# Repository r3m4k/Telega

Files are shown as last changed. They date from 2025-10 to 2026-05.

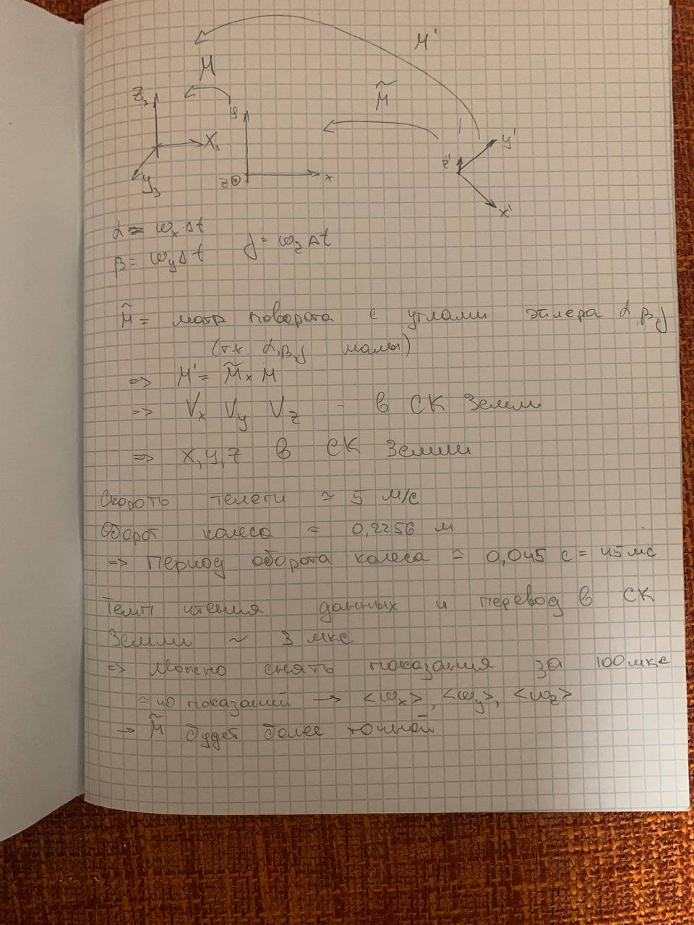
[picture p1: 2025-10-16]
Embedded/Documentation/photo_2024-12-10_16-21-57.jpg

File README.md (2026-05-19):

# Telega

## Структура проекта

Проект состоит из нескольких самостоятельных частей:

- `Embedded` - прошивка для STM32F3Discovery, протокол обмена, драйверы датчиков и прикладная логика МК.
- `Python` - GUI-приложение для ПК, слой связи с МК, сохранение данных и вспомогательные модули анализа.
- `KiCad` - файлы печатной платы. В рамках этого README описывается только наличие раздела, без разбора содержимого.
- `Kompas3d` - механические модели и сборки. Файлы CAD не анализируются подробно.
- `Список комплектующих.csv` - перечень компонентов проекта.

## GUI-приложение для ПК

GUI находится в каталоге `Python` и запускается из `Python/main.py`. Приложение написано на PyQt5 и предназначено для работы с путеизмерительной тележкой через COM-порт: настройка подключения, запуск служебных стадий МК, отображение текущих показаний и сохранение результатов измерений.

### Запуск

Рекомендуемый запуск из корня репозитория:

```bash
python -m venv Python/.venv
Python/.venv/Scripts/pip install -r Python/requirements.txt
Python/.venv/Scripts/python Python/main.py
```

На Linux путь к интерпретатору виртуального окружения будет `Python/.venv/bin/python`.

### Возможности приложения

- выбор директории сохранения и шаблона имени файлов;
- выбор и обновление списка COM-портов;
- запуск рукопожатия с МК после применения настроек;
- запуск калибровки датчиков;
- запуск набора статического буфера перед проездом;
- запуск и завершение измерительного проезда;
- отображение текущих значений `Acc_X`, `Acc_Y`, `Acc_Z`, `Gyro_X`, `Gyro_Y`, `Gyro_Z` и кода ДПП;
- сохранение данных статического буфера и проезда в CSV;
- вывод пользовательских сообщений, предупреждений и ошибок в журнале окна.

Типовой рабочий сценарий описан подробнее в `Python/docs/USER_GUIDE.md`.

### Основные модули

- `Python/main.py` - точка входа, создание `QApplication` и главного окна.
- `Python/gui/main_window.py` - главное окно и state-machine логика пользовательских стадий: настройка, калибровка, статический буфер, готовность к измерению и активное измерение.
- `Python/gui/ui/main_window.ui` - Qt Designer-разметка интерфейса; рядом лежат графические ресурсы `telega.png` и `update.png`.
- `Python/gui/com_port_settings.py` и `Python/gui/saving_params.py` - работа с настройками COM-порта и параметрами сохранения.
- `Python/gui/com_port_reader.py` - мост между GUI и низкоуровневой сессией МК. Запускает отдельный процесс для обмена с устройством и прокидывает данные/события в GUI через Qt-сигналы.
- `Python/gui/data_storage.py` - потоковая запись полученных пакетов `TelegaData` в CSV.
- `Python/gui/data_visualization.py` - обновление LCD-индикаторов текущими значениями телеметрии.
- `Python/telega_session` - проектный слой общения с тележкой: COM-порт, декодер протокола, контроллер команд и функция запуска сессии.
- `Python/async_mc_controller` - более общий асинхронный слой для источников байтов, декодирования, контроллера, шины сигналов, логирования и конфигурации.
- `Python/app_config` и `Python/logger` - конфигурация приложения на Pydantic и настройка логирования.
- `Python/data_analys` и `Python/plotting` - вспомогательные модули для постобработки, фильтрации, расчета траектории и построения графиков.

### Поток данных

После применения настроек главное окно создает конфигурацию COM-порта и запускает `ComPortReader`. Низкоуровневая сессия работает в отдельном процессе через `multiprocessing`, читает байтовый поток с устройства, декодирует пакеты протокола и отправляет в GUI три типа событий: служебные сообщения, телеметрию `TelegaData` и ошибки. Главное окно обновляет индикаторы, пишет данные в открытый CSV-файл и переключает доступные действия пользователя согласно текущей стадии работы.

### Сохраняемые данные

Во время набора статического буфера создается файл вида:

```text
{шаблонное_название}_static_init_{номер_проезда}.csv
```

Во время измерительного проезда создается файл вида:

```text
{шаблонное_название}_measuring_{номер_проезда}.csv
```

CSV пишется в UTF-8 с полями:

```text
PackageNum DppCode AccX AccY AccZ GyroX GyroY GyroZ
```

Настройки приложения сохраняются в `Python/app_config/settings.json`; файл относится к локальным runtime-данным и не обязан храниться в репозитории.

## Прошивка для STM32F3Discovery

Пользовательская часть прошивки расположена в `Embedded/user` и написана как C++-слой поверх STM32F30x Standard Peripheral Library, USB VCP и библиотек датчиков платы STM32F3Discovery. Проект устроен почти как header-only фреймворк: прикладной сценарий находится в `src/main.cpp`, а драйверы, контейнеры, фильтры, протоколы и обвязка периферии вынесены в заголовочные модули `inc`.

### Общая структура

- `src/main.cpp` - точка входа, инициализация оборудования, главный цикл, стадии программы, обработчики команд и системные функции.
- `inc/main.h` - C/C++ мост к STM32 SPL, USB VCP, CMSIS и функциям пользовательского слоя.
- `inc/Common` - общие типы, константы, `TriaxialData` и базовый механизм регистрации обработчиков прерываний.
- `inc/Periph` - GPIO, EXTI и светодиоды платы.
- `inc/Timers` - обертки над аппаратными таймерами STM32, конфигурации и descriptor-классы.
- `inc/Sensors` - драйверы L3GD20, LSM303DLHC и масштабирование датчиков.
- `inc/Filters` - статистика, N-sigma фильтр и фильтр Калмана.
- `inc/DataContainers` - очереди фиксированного размера, включая SPSC-очередь для обмена между IRQ и main.
- `inc/Communication` - сообщения, пакеты, декодеры, USB VCP и USART.
- `inc/aaa_Project_Files` - доменная логика проекта: команды, пакет телеметрии, декодер входящих команд и датчик пройденного пути.

### Инициализация и прерывания

При старте `main()` копирует таблицу векторов прерываний из flash в пользовательскую таблицу `_user_vector_table` в RAM, переключает `SCB->VTOR` на эту таблицу и затем инициализирует оборудование через `InitAll()`. Такой подход позволяет C++-объектам регистрировать собственные обработчики IRQ во время инициализации.

Механизм регистрации прерываний реализован через CRTP-класс `BaseIRQDevice`. Конкретные устройства, например таймеры или EXTI-пины, наследуются от него, сохраняют указатель на активный экземпляр и записывают статический обработчик в пользовательскую таблицу векторов. При срабатывании IRQ статический обработчик перенаправляет вызов в метод `irq_handler()` нужного объекта.

### Основной цикл и стадии программы

Главный цикл прошивки работает как простой диспетчер событий. Сначала он выполняет накопленные отложенные команды из `command_manager.command_queue`, затем при необходимости переключает текущую стадию из `program_stage_queue`, после чего вызывает `init()` новой стадии один раз и `execute()` на каждом проходе цикла.

Поддерживаемые стадии:

- `FooStage` - состояние ожидания: таймеры остановлены, датчики периодически читаются для поддержания их рабочего состояния.
- `CalibrationStage` - калибровка масштабных коэффициентов гироскопа и акселерометра, затем отправка сообщения `END_OF_CALIBRATION`.
- `StaticStage` - статический сбор начальных данных: формируется `InitFrameNum` телеметрических пакетов, после чего отправляется `END_OF_STATIC_INIT`.
- `MeasuringStage` - рабочее измерение: по тику `TIM3` читаются датчики, данные фильтруются, упаковываются и отправляются на ПК.

### Таймеры

В прошивке используются два таймера общего назначения:

- `TIM3` - основной таймер измерений. Его IRQ переключает светодиод `LED9`, выставляет флаг нового периода измерений и увеличивает счетчик времени `tick_counter`.
- `TIM4` - таймер индикации состояния. Его IRQ переключает `LED6` и `LED7`.

Таймеры описаны шаблонными классами `Timer2`, `Timer3`, `Timer4`, которые принимают пользовательский обработчик прерывания как compile-time параметр. Это позволяет вызывать обработчик без виртуальных функций и без runtime-диспетчеризации.

### Датчики и фильтрация

Прошивка работает с датчиками платы STM32F3Discovery:

- `L3GD20` - гироскоп, данные угловой скорости.
- `LSM303DLHC` - акселерометр и температурный датчик; магнитометр в текущей конфигурации отключен.
- `DppSensor` - датчик пройденного пути: импульсы приходят на EXTI-вход `PC1`, направление считывается с `PC3`.

Перед отправкой телеметрии данные акселерометра, гироскопа и температуры проходят через `NSigmaFilter`. Для ускорения и угловой скорости используется фильтр `NSigmaFilter<TriaxialData, 4, 16>`, для температуры - `NSigmaFilter<float, 1, 16>`. Фильтр отбрасывает выбросы по правилу N-sigma и накапливает итоговое среднее.

### Связь с ПК и протокол

Основной канал связи с ПК - USB Virtual COM Port. Входящие данные принимаются в `UserEP3_OUT_Callback()`, преобразуются в `Messages::SizedMessage<VCP_BUFFER_SIZE>` и передаются в `UsbPort`, где поток байтов разбирается `DecoderTelega`.

Входящий командный протокол:

- header: `0xE7 0x7E`;
- format: `0xAB`;
- length: длина поля данных;
- data: код команды;
- checksum: младший байт суммы предыдущих байтов пакета.

`DecoderTelega` отвечает только за входящий поток команд. Он находит команду в списках `urgent_commands` и `deferred_commands` менеджера команд. Срочные команды выполняются сразу в контексте обработчика приема, отложенные команды помещаются в SPSC-очередь и выполняются позже в основном цикле.

Поддерживаемые команды:

- `0xff 0xff` - перезагрузка МК.
- `0xaa 0x00` - переход в `FooStage`.
- `0xaa 0x01` - переход в `CalibrationStage`.
- `0xaa 0x02` - переход в `MeasuringStage`.
- `0xaa 0x03` - переход в `StaticStage`.
- `HANDSHAKE_ACK`, `HEARTBEAT_ACK` - текстовые служебные команды, на которые МК отвечает собственными ACK-сообщениями.

### Исходящие пакеты

Телеметрия отправляется через `TelegaPackage`. Пакет содержит:

- счетчик времени `tick_counter`;
- ускорение `acc_value`;
- угловую скорость `gyro_value`;
- температуру `temp_value`;
- код датчика пройденного пути `dpp_code`;
- контрольную сумму.

Текстовые служебные ответы формируются через `MessagePackage`: подтверждение команды, handshake ACK, heartbeat ACK, сообщение об ошибке, окончание калибровки и окончание статической инициализации.

### Соглашения проекта

Прошивка рассчитана на доверенный ПК-клиент, который отправляет небольшие корректные команды и не перегружает очередь команд. Переполнение очередей и чрезмерная длина входящих пакетов считаются нарушением протокольного соглашения, а не штатным режимом работы. Частота таймера измерений должна быть согласована со временем чтения датчиков, фильтрации и отправки пакета так, чтобы обработка успевала завершиться до следующего периода измерений.

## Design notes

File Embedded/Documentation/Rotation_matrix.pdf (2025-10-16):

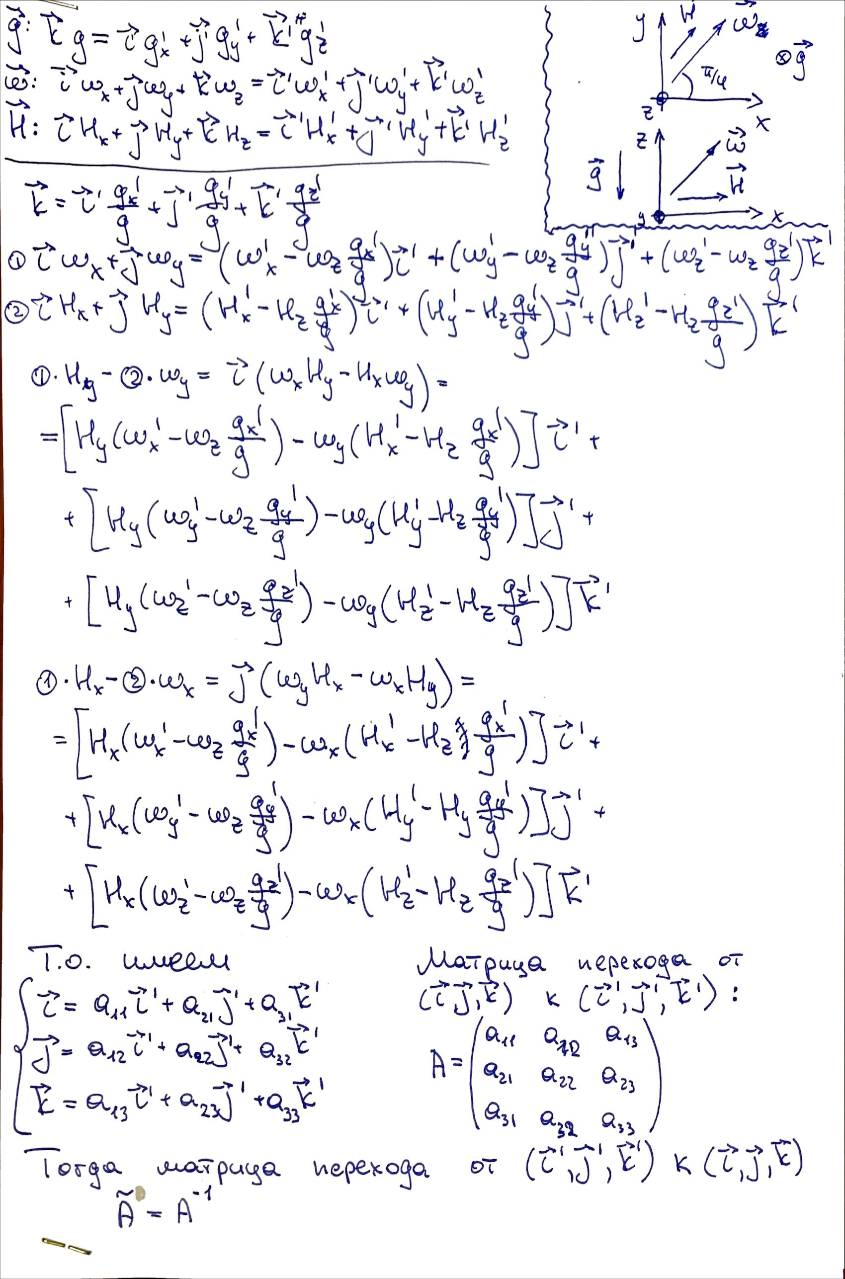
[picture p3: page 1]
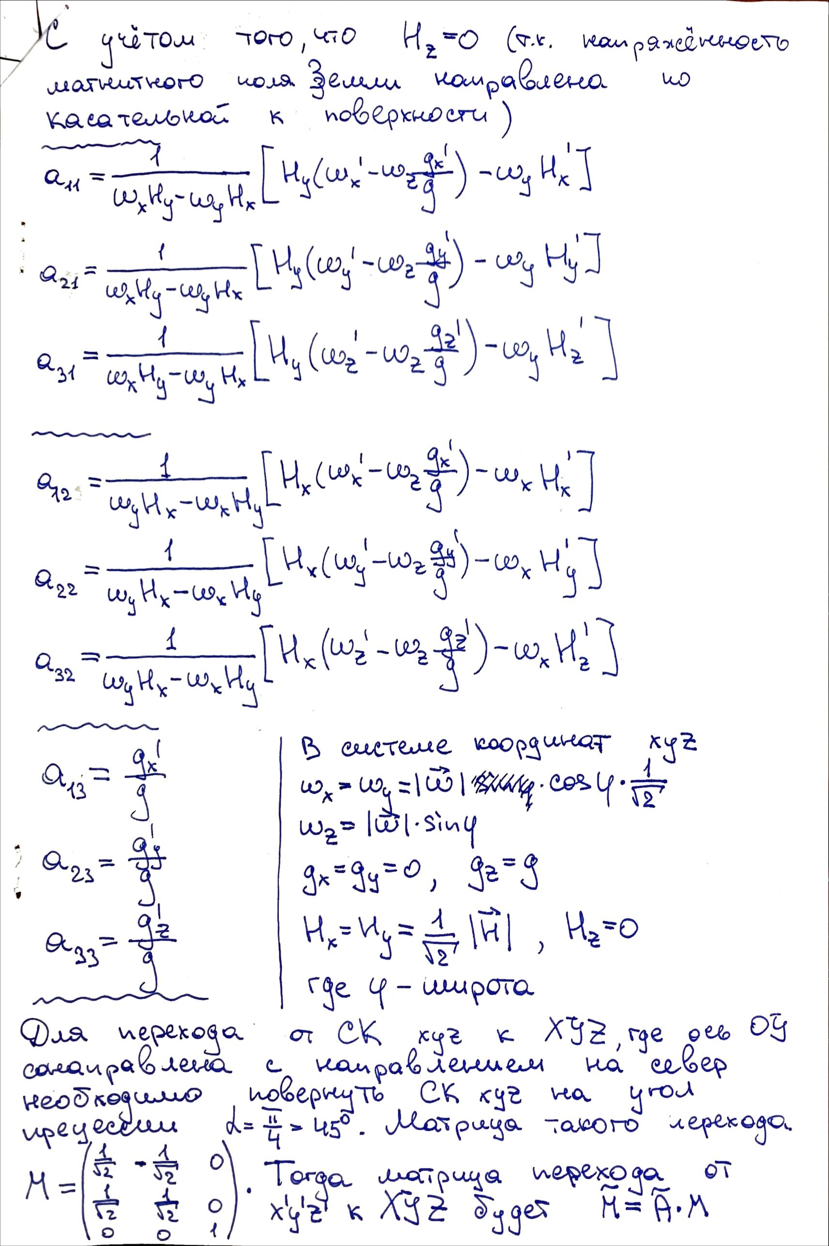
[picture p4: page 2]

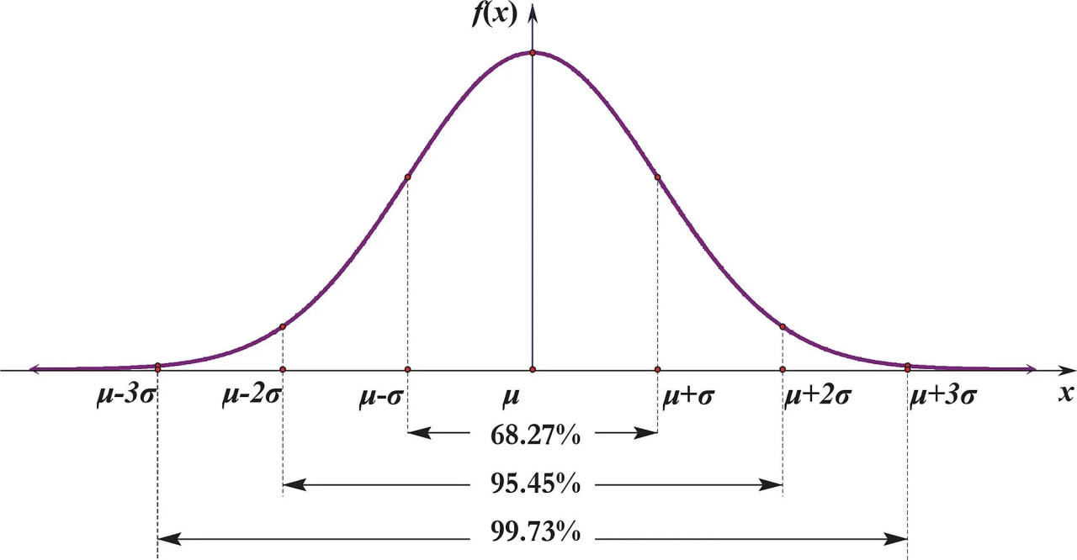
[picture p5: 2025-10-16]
Embedded/Documentation/sigma_rule.jpg

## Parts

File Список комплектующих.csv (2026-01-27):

Номенклатурный номер | Наименование | Бренд | Кол-во | Цена, RUB | Дата доставки | Сумма, RUB
51268 | MF-R135, 1.35А, Предохранитель самовосстанавливающийся, MultiFuse | Bourns | 1 | 20,00 | 3 декабря | 20,00
9000213601 | MTS-101 A-2, Микротумблер ON-OFF SPST 2P 250B/3A | Jietong Switch | 2 | 57,00 | 3 декабря | 114,00
8038550183 | K7815-2000R3 | Mornsun | 1 | 350,00 | 5 декабря | 350,00
36056 | PBD-50 (DS1023-2x25), Гнездо на плату 2.54мм 2х25pin прямое | Connfly | 2 | 30,00 | 3 декабря | 60,00
9000222467 | ВРПИ-М 1,5-(6,3) (ВРПИ-М 1.5-7-0.8), Разъем виброустойчивый плоский 0,5 - 1,5мм² | КВТ | 2 | 12,00 | 3 декабря | 24,00
9001493348 | CDPK0810-101K, 100мкГн, Катушка индуктивности | SCE | 1 | 28,00 | 3 декабря | 28,00
9000565847 | К50-35, 10мкФ, 50В, 105°C, 20%, 5x11мм P:2мм, JRB1H100M02000500110000B, Конденсатор электролитический алюминиевый | JB Capacitors | 1 | 4,00 | 3 декабря | 4,00
9000565854 | К50-35, 22мкФ, 25В, 105°C, 20%, 5x11мм P:2мм, JRB1E220M02000500110000B, Конденсатор электролитический алюминиевый | JB Capacitors | 2 | 4,00 | 3 декабря | 8,00
9000565861 | К50-35, 22мкФ, 50В, 105°C, 20%, 5x11мм P:2мм, JRB1H220M02000500110000B, Конденсатор электролитический алюминиевый | JB Capacitors | 1 | 4,00 | 3 декабря | 4,00
9000461669 | 1N5400, Диод выпрямительный 3А 50В [DO-201AD.] | Diotec | 3 | 18,00 | 3 декабря | 54,00
9001599836 | MAX3232EIDR, Трансивер RS-232, Full-Duplex, 2/2, 250Kbps [SOIC-16.] | Texas Instruments | 2 | 49,00 | 3 декабря | 98,00
8001786468 | K7805-1000R3 | Mornsun | 1 | 190,00 | 5 декабря | 190,00
9001169157 | L7812CV, Стабилизатор напряжения +12В 1.5А [TO-220.] | UMW | 1 | 19,00 | 3 декабря | 19,00
9000811973 | GNL-3012GD, Светодиод зеленый 60° d=3мм 5-10мКд 565нМ (Green) | G-nor | 1 | 9,00 | 3 декабря | 9,00
9000422971 | GNL-3012ED, Светодиод оранжевый 60° d=3мм 8мКд 635нМ (Orange) | G-nor | 1 | 9,00 | 3 декабря | 9,00
9000422970 | GNL-3012YD, Светодиод желтый 60° d=3мм 6мКд 585нМ (Yellow) | G-nor | 1 | 12,00 | 3 декабря | 12,00
9000295626 | MLH-3, Держатель светодиода 3мм металл. | Daier | 3 | 17,00 | 3 декабря | 51,00
9000172308 | 0.33мкФ X7R 16В 10% 0805, CC0805KKX7R7BB334, Конденсатор керамический smd | Yageo | 10 | 5,00 | 3 декабря | 50,00
443350645 | 1 мкФ X7R 16В 10% 0805, GRM21BR71C105K, Конденсатор керамический smd | Murata | 5 | 5,00 | 3 декабря | 25,00
9000896422 | 0.047мкФ X7R 25В 10% 0805, CC0805KRX7R8BB473, Конденсатор керамический smd | Yageo | 5 | 3,00 | 3 декабря | 15,00
9000161208 | 0.25Вт 1206 22 Ом, 1%, RC1206FR-0722RL, Чип резистор (SMD) | Yageo | 10 | 2,00 | 3 декабря | 20,00
 |  |  |  |  | Сумма товаров в заказе, RUB | 1164,00
 |  |  |  |  | Кол-во товаров в заказе | 21

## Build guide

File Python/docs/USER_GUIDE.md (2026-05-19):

# Руководство пользователя

## Назначение

Приложение "Путеизмерительная тележка" предназначено для настройки подключения к микроконтроллеру, калибровки датчиков и сохранения данных проездов в CSV-файлы.

Окно приложения состоит из нескольких основных зон:

- параметры сохранения данных;
- выбор COM-порта;
- индикаторы текущих показаний датчиков;
- кнопки управления процедурой измерений;
- журнал информационных сообщений;
- номер текущего проезда.

## Подготовка к работе

Перед запуском измерений убедитесь, что:

- микроконтроллер подключён к компьютеру;
- COM-порт устройства доступен в системе;
- выбрана директория, куда можно записывать файлы;
- задано шаблонное название файлов.

## Настройка сохранения и подключения

1. В поле `Директория сохранения данных` укажите папку для результатов.
2. В поле `Шаблонное название файлов` укажите базовое имя файлов.
3. В списке `Выбранный com порт` выберите порт микроконтроллера.
4. Если нужного порта нет в списке, нажмите кнопку обновления рядом со списком COM-портов.
5. Нажмите `Применить`.

После применения настроек приложение:

- блокирует изменение параметров сохранения и COM-порта;
- запускает сессию связи с микроконтроллером;
- ожидает рукопожатие с МК;
- выводит результат в журнал информационных сообщений.

Если рукопожатие выполнено успешно, можно запускать калибровку.

## Калибровка датчиков

1. Нажмите `Начать калибровку датчиков`.
2. Дождитесь завершения процедуры.
3. После завершения приложение покажет информационное окно `Калибровка завершена`.
4. Подтвердите сообщение нажатием `OK`.

После калибровки приложение переходит к этапу набора статического буфера.

Повторная калибровка доступна после завершения текущего проезда. При повторной калибровке приложение предупреждает, что текущий цикл подготовки к измерениям будет сброшен и статический буфер нужно будет набрать заново.

## Набор статического буфера

Перед каждым измерением необходимо заново набрать статический буфер.

1. Убедитесь, что тележка находится в состоянии, подходящем для набора статического буфера.
2. Нажмите `Начать сбор статического буфера`.
3. Дождитесь завершения процедуры.
4. После завершения приложение покажет информационное окно `Статический буфер набран`.
5. Подтвердите сообщение нажатием `OK`.

Во время набора статического буфера приложение сохраняет данные в файл:

```text
{шаблонное_название}_static_init_{номер_проезда}.csv
```

Например:

```text
telega_2026-05-19_static_init_1.csv
```

Повторный запуск набора статического буфера во время активной процедуры блокируется.

## Выполнение проезда

После завершения набора статического буфера приложение готово к измерению.

1. Нажмите `Начать проезд`.
2. Выполните проезд тележки.
3. Для завершения измерения нажмите `Завершить проезд`.

Во время проезда приложение сохраняет данные в файл:

```text
{шаблонное_название}_measuring_{номер_проезда}.csv
```

Например:

```text
telega_2026-05-19_measuring_1.csv
```

После завершения проезда:

- текущий CSV-файл закрывается;
- номер текущего проезда увеличивается на 1;
- приложение возвращается к этапу набора статического буфера.

## Последовательность работы

Типовой рабочий цикл выглядит так:

1. Задать директорию сохранения, шаблон файла и COM-порт.
2. Нажать `Применить`.
3. Дождаться успешного рукопожатия с МК.
4. Нажать `Начать калибровку датчиков`.
5. Дождаться сообщения о завершении калибровки.
6. Нажать `Начать сбор статического буфера`.
7. Дождаться сообщения о завершении набора статического буфера.
8. Нажать `Начать проезд`.
9. После окончания проезда нажать `Завершить проезд`.
10. Для следующего проезда снова набрать статический буфер.

## Индикаторы и журнал сообщений

В зоне показаний датчиков отображаются текущие значения:

- `Acc_X`, `Acc_Y`, `Acc_Z`;
- `Gyro_X`, `Gyro_Y`, `Gyro_Z`;
- `Код ДПП`.

Справа расположен журнал `Информационные сообщения`. В него выводятся важные события:

- применение настроек;
- ожидание и результат рукопожатия;
- запуск и завершение калибровки;
- запуск и завершение набора статического буфера;
- запуск и завершение проезда;
- предупреждения и ошибки.

Номер текущего проезда отображается в верхней части окна. Он изменяется автоматически после завершения проезда.

## Ограничения действий

Приложение контролирует порядок работы и предупреждает пользователя, если действие сейчас недоступно.

Нельзя:

- запускать калибровку до применения настроек;
- начинать набор статического буфера до успешной калибровки;
- начинать проезд до завершения набора статического буфера;
- повторно запускать набор статического буфера во время активного набора;
- запускать новый проезд, пока предыдущий не завершён;
- менять параметры сохранения и COM-порт после начала рабочей сессии.

## Завершение работы

Для завершения работы закройте окно приложения стандартной кнопкой закрытия.

При закрытии приложение:

- останавливает сессию связи с микроконтроллером;
- завершает чтение очередей данных;
- закрывает открытый CSV-файл, если он был открыт;
- освобождает ресурсы COM-сессии.

Если проезд был активен, перед закрытием рекомендуется сначала нажать `Завершить проезд`, чтобы текущий файл измерений был закрыт штатно.

## Возможные ошибки

Если приложение сообщает об ошибке задания параметров, проверьте:

- существует ли директория сохранения или можно ли её создать;
- доступна ли директория для записи;
- задано ли корректное шаблонное название файлов;
- выбран ли COM-порт.

Если рукопожатие с МК не выполнено:

- проверьте физическое подключение устройства;
- убедитесь, что выбран правильный COM-порт;
- проверьте, не занят ли порт другой программой;
- повторно примените настройки после устранения причины.

Если возникла ошибка записи CSV:

- проверьте свободное место на диске;
- убедитесь, что файлы результатов не открыты в другой программе с блокировкой записи;
- проверьте права записи в директорию сохранения.

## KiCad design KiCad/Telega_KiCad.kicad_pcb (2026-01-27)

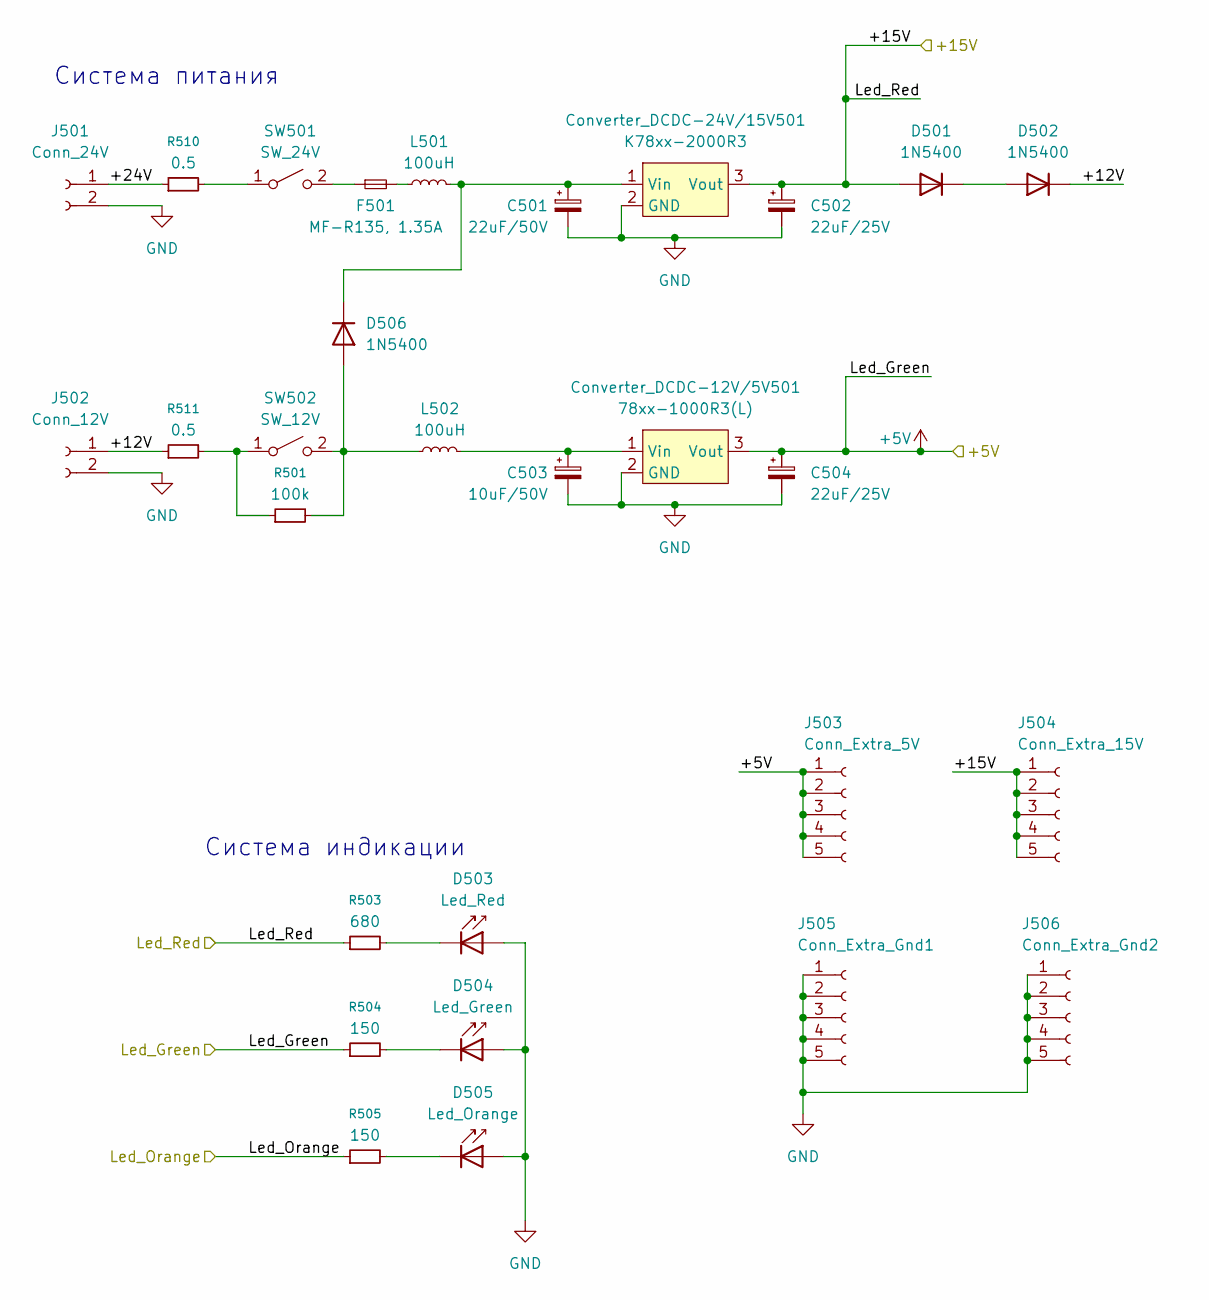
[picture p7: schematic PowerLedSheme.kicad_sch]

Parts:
C501: 22uF/50V; CP_Radial_D8.0mm_P5.00mm
C502, C504: 22uF/25V; CP_Radial_D8.0mm_P5.00mm
C503: 10uF/50V; CP_Radial_D8.0mm_P5.00mm
Converter_DCDC-12V/5V501: 78xx-1000R3(L); Converter_DCDC_RECOM_R-78B-2.0_THT
Converter_DCDC-24V/15V501: K78xx-2000R3; Converter_DCDC_RECOM_R-78B-2.0_THT
D501, D502, D506: 1N5400; D_DO-201AD_P15.24mm_Horizontal
D503: Led_Red; SolderWire-1sqmm_1x02_P5.4mm_D1.4mm_OD2.7mm
D504: Led_Green; SolderWire-1sqmm_1x02_P5.4mm_D1.4mm_OD2.7mm
D505: Led_Orange; SolderWire-1sqmm_1x02_P5.4mm_D1.4mm_OD2.7mm
F501: MF-R135, 1.35А; Fuse_Bourns_MF-RG300
J501: Conn_24V; Molex_KK-254_AE-6410-02A_1x02_P2.54mm_Vertical
J502: Conn_12V; Molex_KK-254_AE-6410-02A_1x02_P2.54mm_Vertical
J503: Conn_Extra_5V; SolderWire-1sqmm_1x05_P5.4mm_D1.4mm_OD2.7mm
J504: Conn_Extra_15V; SolderWire-1sqmm_1x05_P5.4mm_D1.4mm_OD2.7mm
J505: Conn_Extra_Gnd1; SolderWire-1sqmm_1x05_P5.4mm_D1.4mm_OD2.7mm
J506: Conn_Extra_Gnd2; SolderWire-1sqmm_1x05_P5.4mm_D1.4mm_OD2.7mm
L501, L502: 100uH; L_Radial_D9.5mm_P5.00mm_Fastron_07HVP
R501: 100k; R_Axial_DIN0516_L15.5mm_D5.0mm_P25.40mm_Horizontal
R503: 680; R_Axial_DIN0516_L15.5mm_D5.0mm_P25.40mm_Horizontal
R504, R505: 150; R_Axial_DIN0516_L15.5mm_D5.0mm_P25.40mm_Horizontal
R510, R511: 0.5; R_Axial_Power_L38.0mm_W6.4mm_P40.64mm
SW501: SW_24V; SolderWire-1.5sqmm_1x02_P7.8mm_D1.7mm_OD3.9mm
SW502: SW_12V; SolderWire-1.5sqmm_1x02_P7.8mm_D1.7mm_OD3.9mm

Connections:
+5V: C504.1, Converter_DCDC-12V/5V501.3 (Vout), J503.1, J503.2, J503.3, J503.4, J503.5, R504.1; also elsewhere on the board
/+15V: C502.1, Converter_DCDC-24V/15V501.3 (Vout), D501.2 (A), J504.1, J504.2, J504.3, J504.4, J504.5, R503.1; also elsewhere on the board
/Led_Orange: R505.1; also elsewhere on the board
/PowerLedSheme/+12V: D502.1 (K), J502.1, R511.1
/PowerLedSheme/+24V: J501.1, R510.1
GND: C501.2, C502.2, C503.2, C504.2, Converter_DCDC-12V/5V501.2 (GND), Converter_DCDC-24V/15V501.2 (GND), D503.2 (A), D504.2 (A), D505.2 (A), J501.2, J502.2, J505.1, J505.2, J505.3, J505.4, J505.5, J506.1, J506.2, J506.3, J506.4, J506.5; also elsewhere on the board
unnamed: C503.1, Converter_DCDC-12V/5V501.1 (Vin), L502.2
unnamed: C501.1, Converter_DCDC-24V/15V501.1 (Vin), D506.1 (K), L501.2
unnamed: D501.1 (K), D502.2 (A)
unnamed: D503.1 (K), R503.2
unnamed: D504.1 (K), R504.2
unnamed: D505.1 (K), R505.2
unnamed: D506.2 (A), L502.1, R501.2, SW502.2 (B)
unnamed: F501.2, L501.1
unnamed: R510.2, SW501.1 (A)
unnamed: F501.1, SW501.2 (B)
unnamed: R501.1, R511.2, SW502.1 (A)

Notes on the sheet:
Система питания
Система индикации

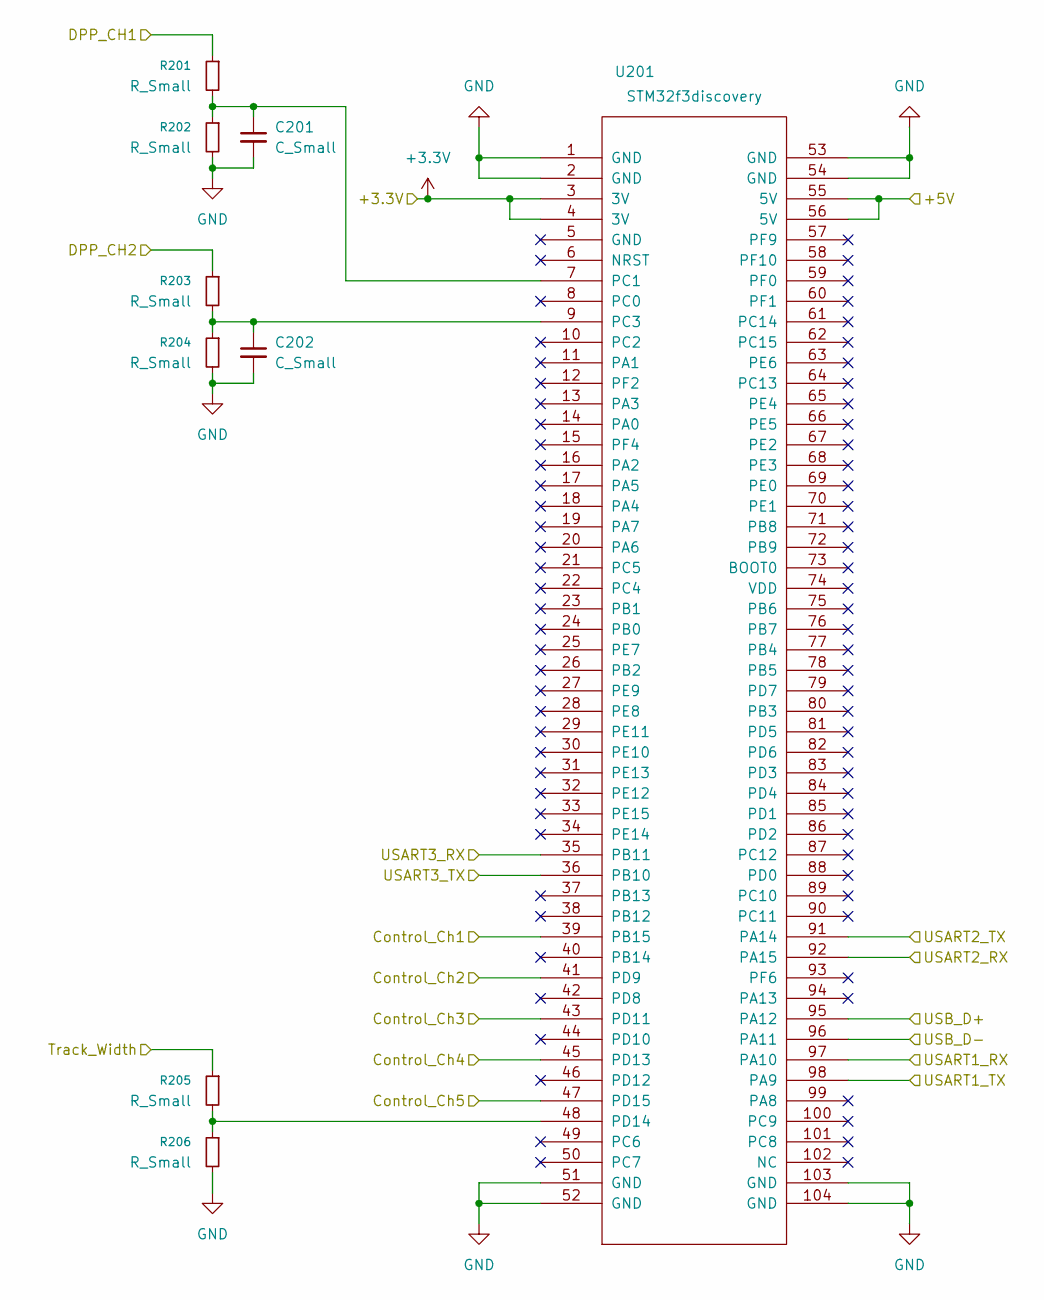
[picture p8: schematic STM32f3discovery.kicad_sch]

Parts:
C201, C202: C_Small; CP_Radial_D8.0mm_P5.00mm
R201, R202, R203, R204, R205, R206: R_Small; R_Axial_DIN0207_L6.3mm_D2.5mm_P15.24mm_Horizontal
U201: STM32f3discovery

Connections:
+3.3V: U201.3 (3V), U201.4 (3V)
+5V: U201.55 (5V), U201.56 (5V); also elsewhere on the board
/Control_Ch1: U201.39 (PB15); also elsewhere on the board
/Control_Ch2: U201.41 (PD9); also elsewhere on the board
/Control_Ch3: U201.43 (PD11); also elsewhere on the board
/Control_Ch4: U201.45 (PD13); also elsewhere on the board
/Control_Ch5: U201.47 (PD15); also elsewhere on the board
/DPP_CH1: R201.1; also elsewhere on the board
/DPP_CH2: R203.1; also elsewhere on the board
/Track_Width: R205.1; also elsewhere on the board
/USART1_RX: U201.97 (PA10); also elsewhere on the board
/USART1_TX: U201.98 (PA9); also elsewhere on the board
/USART2_RX: U201.92 (PA15); also elsewhere on the board
/USART2_TX: U201.91 (PA14); also elsewhere on the board
/USART3_RX: U201.35 (PB11); also elsewhere on the board
/USART3_TX: U201.36 (PB10); also elsewhere on the board
/USB_D+: U201.95 (PA12); also elsewhere on the board
/USB_D-: U201.96 (PA11); also elsewhere on the board
GND: C201.2, C202.2, R202.2, R204.2, R206.2, U201.1 (GND), U201.2 (GND), U201.51 (GND), U201.52 (GND), U201.53 (GND), U201.54 (GND), U201.103 (GND), U201.104 (GND); also elsewhere on the board
unnamed: C201.1, R201.2, R202.1, U201.7 (PC1)
unnamed: C202.1, R203.2, R204.1, U201.9 (PC3)
unnamed: R205.2, R206.1, U201.48 (PD14)

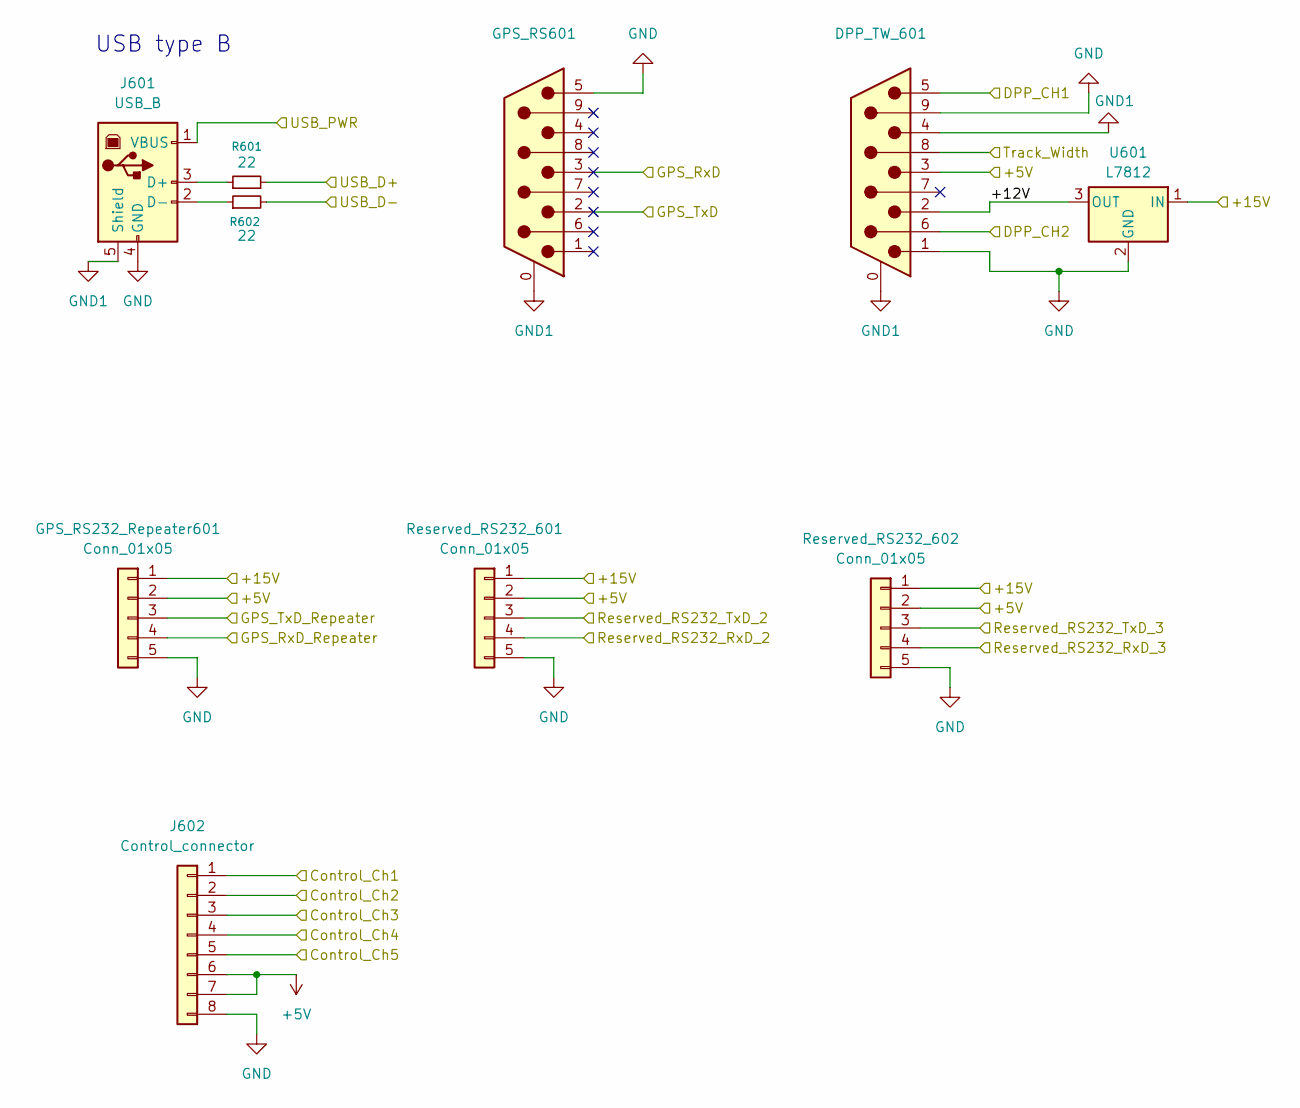
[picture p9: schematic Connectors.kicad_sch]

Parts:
DPP_TW_601: DE9_Pins_MountingHoles; DSUB-9_Pins_Horizontal_P2.77x2.84mm_EdgePinOffset7.70mm_Hou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
GPS_RS232_Repeater601: Conn_01x05; SolderWire-1sqmm_1x05_P5.4mm_D1.4mm_OD2.7mm
GPS_RS601: DE9_Pins_MountingHoles; DSUB-9_Pins_Horizontal_P2.77x2.84mm_EdgePinOffset7.70mm_Hou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
J601: USB_B; USB_B_Lumberg_2411_02_Horizontal
J602: Control_connector; Molex_KK-254_AE-6410-08A_1x08_P2.54mm_Vertical
R601, R602: 22; R_1206_3216Metric
Reserved_RS232_601, Reserved_RS232_602: Conn_01x05; SolderWire-1sqmm_1x05_P5.4mm_D1.4mm_OD2.7mm
U601: L7812; TO-220-3_Vertical

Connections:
+5V: DPP_TW_601.3, GPS_RS232_Repeater601.2, J602.6, J602.7, Reserved_RS232_601.2, Reserved_RS232_602.2; also elsewhere on the board
/+15V: GPS_RS232_Repeater601.1, Reserved_RS232_601.1, Reserved_RS232_602.1, U601.1 (IN); also elsewhere on the board
/Connectors/+12V: DPP_TW_601.2, U601.3 (OUT)
/Control_Ch1: J602.1; also elsewhere on the board
/Control_Ch2: J602.2; also elsewhere on the board
/Control_Ch3: J602.3; also elsewhere on the board
/Control_Ch4: J602.4; also elsewhere on the board
/Control_Ch5: J602.5; also elsewhere on the board
/DPP_CH1: DPP_TW_601.5; also elsewhere on the board
/DPP_CH2: DPP_TW_601.6; also elsewhere on the board
/GPS_RxD: GPS_RS601.3; also elsewhere on the board
/GPS_RxD_Repeater: GPS_RS232_Repeater601.4; also elsewhere on the board
/GPS_TxD: GPS_RS601.2; also elsewhere on the board
/GPS_TxD_Repeater: GPS_RS232_Repeater601.3; also elsewhere on the board
/Led_Orange: J601.1 (VBUS); also elsewhere on the board
/Reserved_RS232_RxD_2: Reserved_RS232_601.4; also elsewhere on the board
/Reserved_RS232_RxD_3: Reserved_RS232_602.4; also elsewhere on the board
/Reserved_RS232_TxD_2: Reserved_RS232_601.3; also elsewhere on the board
/Reserved_RS232_TxD_3: Reserved_RS232_602.3; also elsewhere on the board
/Track_Width: DPP_TW_601.8; also elsewhere on the board
/USB_D+: R601.2; also elsewhere on the board
/USB_D-: R602.2; also elsewhere on the board
GND: DPP_TW_601.1, DPP_TW_601.9, GPS_RS232_Repeater601.5, GPS_RS601.5, J601.4 (GND), J602.8, Reserved_RS232_601.5, Reserved_RS232_602.5, U601.2 (GND); also elsewhere on the board
GND1: DPP_TW_601.0 (PAD), DPP_TW_601.4, GPS_RS601.0 (PAD), J601.5 (Shield)
unnamed: J601.3 (D+), R601.1
unnamed: J601.2 (D-), R602.1

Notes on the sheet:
USB type B

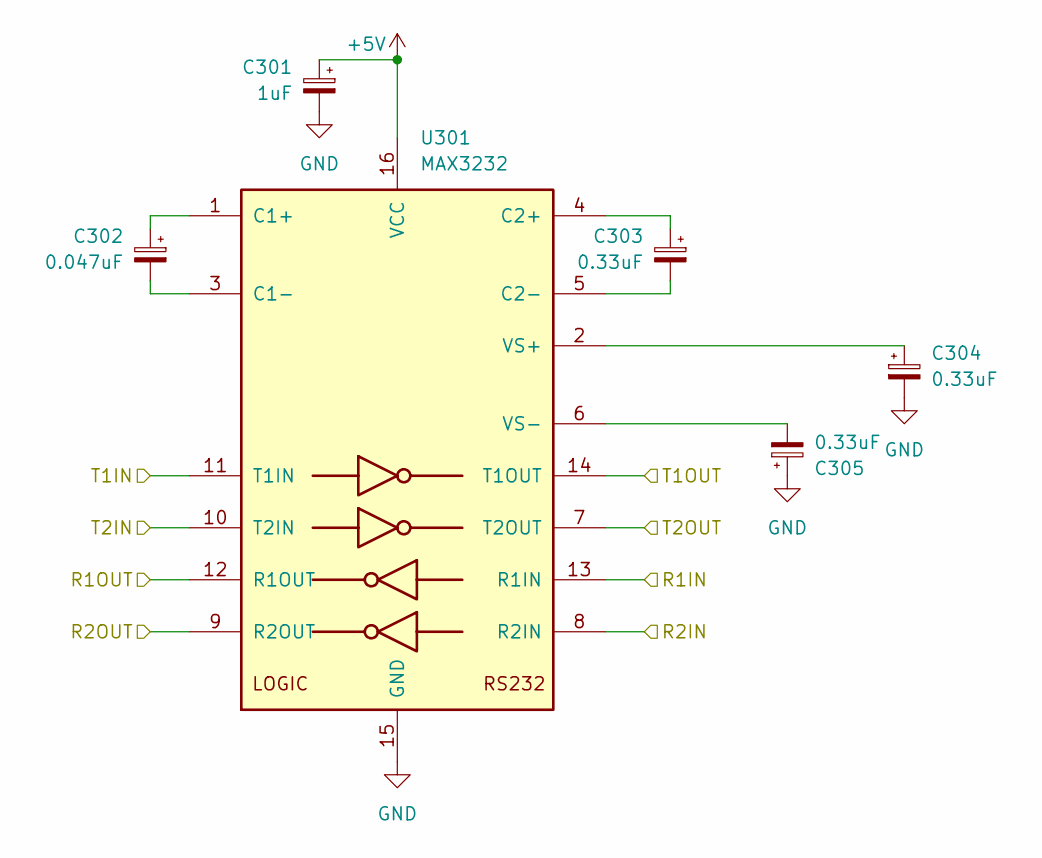
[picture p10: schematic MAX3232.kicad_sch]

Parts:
C301: 1uF; CP_EIA-2012-12_Kemet-R_HandSolder
C302: 0.047uF; CP_EIA-2012-12_Kemet-R_HandSolder
C303, C304, C305: 0.33uF; CP_EIA-2012-12_Kemet-R_HandSolder
U301: MAX3232; SOIC-16W_7.5x10.3mm_P1.27mm

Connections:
+5V: C301.1, U301.16 (VCC); also elsewhere on the board
/GPS_RxD: U301.14 (T1OUT); also elsewhere on the board
/GPS_RxD_Repeater: U301.7 (T2OUT); also elsewhere on the board
/GPS_TxD: U301.13 (R1IN); also elsewhere on the board
/GPS_TxD_Repeater: U301.8 (R2IN); also elsewhere on the board
/USART1_RX: U301.9 (R2OUT), U301.12 (R1OUT); also elsewhere on the board
/USART1_TX: U301.10 (T2IN), U301.11 (T1IN); also elsewhere on the board
GND: C301.2, C304.2, C305.1, U301.15 (GND); also elsewhere on the board
unnamed: C302.1, U301.1 (C1+)
unnamed: C302.2, U301.3 (C1-)
unnamed: C303.1, U301.4 (C2+)
unnamed: C303.2, U301.5 (C2-)
unnamed: C304.1, U301.2 (VS+)
unnamed: C305.2, U301.6 (VS-)

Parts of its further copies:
C401: 1uF; CP_EIA-2012-12_Kemet-R_HandSolder
C402: 0.047uF; CP_EIA-2012-12_Kemet-R_HandSolder
C403, C404, C405: 0.33uF; CP_EIA-2012-12_Kemet-R_HandSolder
U401: MAX3232; SOIC-16W_7.5x10.3mm_P1.27mm

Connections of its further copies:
+5V: C401.1, U401.16 (VCC); also elsewhere on the board
/Reserved_RS232_RxD_2: U401.14 (T1OUT); also elsewhere on the board
/Reserved_RS232_RxD_3: U401.7 (T2OUT); also elsewhere on the board
/Reserved_RS232_TxD_2: U401.13 (R1IN); also elsewhere on the board
/Reserved_RS232_TxD_3: U401.8 (R2IN); also elsewhere on the board
/USART2_RX: U401.12 (R1OUT); also elsewhere on the board
/USART2_TX: U401.11 (T1IN); also elsewhere on the board
/USART3_RX: U401.9 (R2OUT); also elsewhere on the board
/USART3_TX: U401.10 (T2IN); also elsewhere on the board
GND: C401.2, C404.2, C405.1, U401.15 (GND); also elsewhere on the board
unnamed: C402.1, U401.1 (C1+)
unnamed: C402.2, U401.3 (C1-)
unnamed: C403.1, U401.4 (C2+)
unnamed: C403.2, U401.5 (C2-)
unnamed: C404.1, U401.2 (VS+)
unnamed: C405.2, U401.6 (VS-)

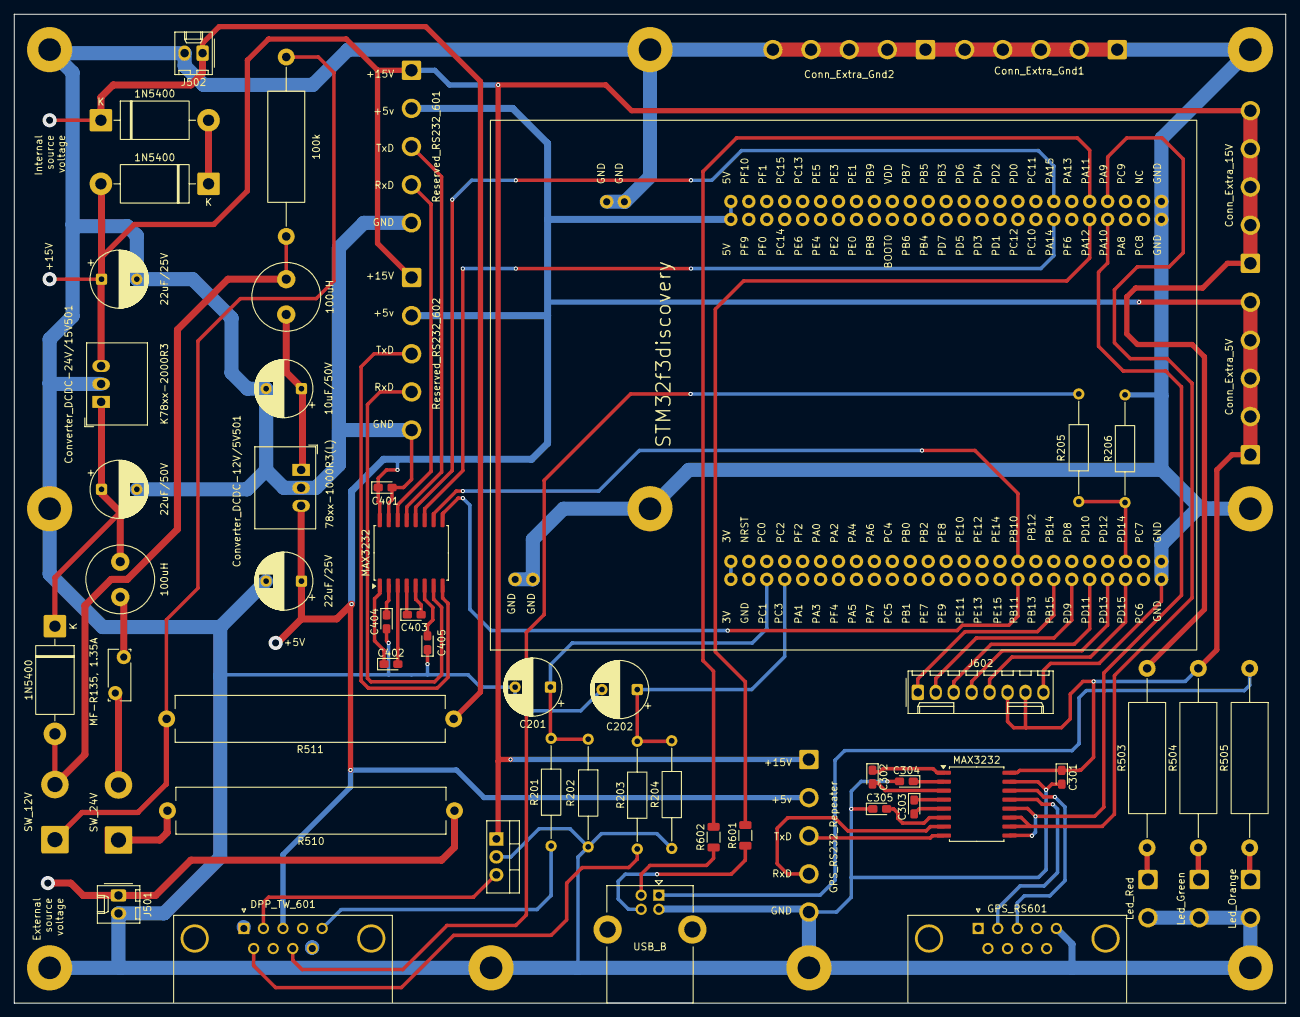
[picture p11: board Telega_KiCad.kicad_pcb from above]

Board: 2 copper layers, 180.0 x 140.0 mm, 60 parts (0 on the bottom side), 61 nets.

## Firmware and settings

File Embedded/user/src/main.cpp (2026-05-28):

/* Includes H files ----------------------------------------------------------*/
#include "main.h"

/* Includes HPP files --------------------------------------------------------*/
#include "Consts.hpp"
#include "GPTimers.hpp"
#include "Leds.hpp"
#include "L3GD20.hpp"
#include "LSM303DLHC.hpp"
#include "DppSensor.hpp"
#include "TelegaPackage.hpp"

#include "RingBuffer.hpp"
#include "UsbPort.hpp"
#include "MessagePackage.hpp"
#include "CommandProcessing.hpp"
#include "NSigmaFilter.hpp"

// ----------------------------------------------------------------------------
//
// Standalone STM32F3 empty sample (trace via NONE).
//
// Trace support is enabled by adding the TRACE macro definition.
// By default the trace messages are forwarded to the NONE output,
// but can be rerouted to any device or completely suppressed, by
// changing the definitions required in system/src/diag/trace_impl.c
// (currently OS_USE_TRACE_ITM, OS_USE_TRACE_SEMIHOSTING_DEBUG/_STDOUT).
//

/* #global variables -----------------------------------------*/
RCC_ClocksTypeDef RCC_Clocks; // structure used for setting up the SysTick Interrupt

// Unused global variables that have to be included to ensure correct compiling
// ###### DO NOT CHANGE ######
// ===============================================================================
__IO uint32_t TimingDelay = 0;                     // used with the Delay function
__IO uint8_t DataReady = 0;
__IO uint32_t USBConnectTimeOut = 100;
__IO uint32_t UserButtonPressed = 0;
__IO uint8_t PrevXferComplete = 1;
__IO uint8_t buttonState;
// ===============================================================================


/* Defines -------------------------------------------------------------------*/
#define IST_VECTORS_NUM     98      // Количество векторов прерываний
#define InitFrameNum        256     // Количество пакетов для выставки

/* Global variables ---------------------------------------------------------*/

typedef void
(* const pHandler)(void);

extern pHandler __isr_vectors[];

/* ****************************************************************************
 * Пользовательские переменные
 *************************************************************************** */

/**
 * @brief   RAM-копия таблицы векторов прерываний.
 * @details 98 векторов занимают 392 байта, поэтому VTOR должен указывать на
 *          адрес, выровненный по ближайшей большей степени двойки: 512 байт.
 */
__attribute__((aligned(512)))
_user_pHandler _user_vector_table[IST_VECTORS_NUM] = {0};

// ----------------------------------------------------------------------------

// Необходимые счётчики и флаг
uint32_t tick_counter = 0;
volatile bool timer_tick_flag = false;

// Счётчик, необходимый для снижения частоты опроса температурного датчика
uint8_t sensor_reading_counter = 0;     

// ----------------------------------------------------------------------------

// Светодиоды на плате
STM_CppLib::Leds leds;

// Обработчик поступивших команд
Commands::CommandManager command_manager;

// Интерфейсы связи
STM_CppLib::UsbPort::UsbPort com_port;

// Используемые таймеры -------------------------------------------------------

// Таймер для чтения данных
STM_CppLib::STM_Timer::Timer3<[](){
    /* Объявление лямбды, которая будет вызываться в прерывании */
    leds.ChangeLedStatus(LED9);
    timer_tick_flag = true;
    tick_counter++;
}>  timer3;

// Таймер для мерцания светодиодами LED6, LED7
STM_CppLib::STM_Timer::Timer4<[](){
    /* Объявление лямбды, которая будет вызываться в прерывании */
    leds.ChangeLedStatus(LED6);
    leds.ChangeLedStatus(LED7);
}>  timer4;     // Таймер для мерцания светодиодами LED6, LED7


/* ****************************************************************************
 * Объявление датчиков, используемых фильтров и пакетов данных
 *
 * Конфигурация датчика пройденного пути:
 * PinPulse:     PC1
 * PinDirection: PC3
 *************************************************************************** */

STM_CppLib::L3GD20      sensor_L3GD20;          // Встроенный гироскоп
STM_CppLib::LSM303DLHC  sensor_LSM303DLHC;      // Встроенный датчик с акселерометром,
                                                // магнитным и температурным датчиками

// Определение пинов для датчика ДПП ------------------------------------------
using PinPulse_t = STM_CppLib::STM_GPIO::GPIO_Pin_EXTI
    <STM_CppLib::STM_GPIO::GPIO_Port::PortC, GPIO_PinSource1, dpp_irq_handler>;

using PinDirection_t = STM_CppLib::STM_GPIO::GPIO_Pin
    <STM_CppLib::STM_GPIO::GPIO_Port::PortC, GPIO_PinSource3>;

Dpp::DppSensor<PinPulse_t, PinDirection_t> dpp_sensor;

// Используемые фильтры
NSigmaFilter<TriaxialData, 4, 16> filter_acc(2.0);     // Фильтр ускорений
NSigmaFilter<TriaxialData, 4, 16> filter_gyro(2.0);    // Фильтр угловой скорости 
NSigmaFilter<float, 1, 16>        filter_temp(2.0);    // Фильтр температуры

// Значения ускорений, угловой скорости и температуры для отправки
TriaxialData acc_value;
TriaxialData gyro_value;
float temp_value;

// Посылка данных
// TODO: в дальнейшем, надо добавить пульт 
Packages::TelegaPackage telega_package(
    &tick_counter, &acc_value, &gyro_value, &temp_value, &dpp_sensor.dpp_code
);

/* ****************************************************************************
 * Описание стадий программы
 *************************************************************************** */

class ProgramStage{
    CommandHandlerFunc init_func;
    CommandHandlerFunc execute_func;
    
public:
    bool is_init = false;

    ProgramStage(CommandHandlerFunc _init_func, CommandHandlerFunc _execute_func):
        init_func(_init_func), execute_func(_execute_func) {}

    void init(){
        init_func();
        is_init = true;
    }

    void execute(){
        execute_func();
    }
};

// -------------------------------------------------------------------------------

// Очередь стадий программ (используется для смены стадий программ).
RingBuffer<ProgramStage*, 2> program_stage_queue;

// Поддерживаемые стадии программы
ProgramStage FooStage(FooStage_init, FooStage_execute);
ProgramStage CalibrationStage(CalibrationStage_init, CalibrationStage_execute);
ProgramStage StaticStage(StaticStage_init, StaticStage_execute);
ProgramStage MeasuringStage(MeasuringStage_init, MeasuringStage_execute);


/* **************************************************************************** */

int main()
{
    /* ***************************************************************************
    * Загрузим собственную таблицу прерываний для возможности её модификации
    *************************************************************************** */

    __disable_irq();    // Отключим прерывания

    // Скопируем исходную таблицу прерываний
    memcpy(_user_vector_table, __isr_vectors, IST_VECTORS_NUM * sizeof(pHandler));

    SCB->VTOR = (uint32_t)_user_vector_table;

    __DSB();    // Ожидаем завершения записи в регистр VTOR
    __ISB();    // Сбрасываем конвейер команд, чтобы следующие инструкции и прерывания
                // использовали новую таблицу векторов

    __enable_irq();     // Включим прерывания

    // ---------------------------------------------------------------------------

    // Получаем текущие значения тактовых частот системы и настроим
    // SysTick для генерации прерываний с периодом 1 мс
    // Если конфигурация SysTick завершилась ошибкой – входим в бесконечный цикл
	RCC_GetClocksFreq(&RCC_Clocks);
	if (SysTick_Config(RCC_Clocks.HCLK_Frequency / 1000))
		while(true) {}
    
    // ---------------------------------------------------------------------------

    // Инициализируем всё оборудования
    InitAll();             
    
    // Поморгаем светодиодами после успешной инициализации
    leds.ToggleLeds();

    // ---------------------------------------------------------------------------

    // Изначально добавим FooStage в program_stage_queue
    program_stage_queue.put(&FooStage);
    ProgramStage* current_stage_ptr = &FooStage;

    // ---------------------------------------------------------------------------
    // Основной цикл программы
    while (true)
    {
        // Выполним все поступившие команды при их наличии
        while (!command_manager.command_queue.is_empty()){
            auto command = command_manager.command_queue.get();
            command.execute();
        }

        // Сменим current_stage_ptr, если есть элементы в очереди program_stage_queue
        if(!program_stage_queue.is_empty()){
            current_stage_ptr->is_init = false;     // Сбросим флаг у текущей стадии
            current_stage_ptr = program_stage_queue.get();
        }

        /* ***********************************************************************
        ШАБЛОН ОТРАБОТКИ СТАДИИ ПРОГРАММЫ:
        Каждая стадия (ProgramStage) отрабатывается по единому принципу:
        1. ИНИЦИАЛИЗАЦИЯ СТАДИИ (однократное выполнение при входе в стадию)
        2. ЦИКЛИЧЕСКОЕ ВЫПОЛНЕНИЕ ОСНОВНОЙ ЛОГИКИ СТАДИИ
        *********************************************************************** */

        if (!current_stage_ptr->is_init){
            current_stage_ptr->init();
        }
        current_stage_ptr->execute();        
    }
}

// -------------------------------------------------------------------------------
// Инициализация оборудования
// -------------------------------------------------------------------------------
void InitAll(){
    leds.Init();
    leds.LedsOn();

    sensor_L3GD20.Init();
    sensor_LSM303DLHC.Init();
    dpp_sensor.Init();
    
    com_port.Init();

    // // Настройка основного таймера с периодом счёта в 250 мс (4 Гц)
    // uint32_t tim3_period = 2500 - 1;
    // Настройка основного таймера с периодом счёта в 100 мс (10 Гц)
    uint32_t tim3_period = 1000 - 1;
    timer3.Init(tim3_period);

    // Настройка таймера для мерцания светодиодами с периодом счёта в 2 с
    uint32_t tim4_period = 20000 - 1;
    timer4.Init(tim4_period);
}

// -------------------------------------------------------------------------------
// Обработчик прерывания от линии Dpp_Channel_1
// -------------------------------------------------------------------------------
void dpp_irq_handler(){
    dpp_sensor.process_front();
}

// -------------------------------------------------------------------------------
// Функции для отработки стадий программы
// -------------------------------------------------------------------------------

// Функция для инициализации FooStage
void FooStage_init(){
    // Выключим все таймеры
    timer3.Stop();
    timer3.ResetCounter();
    timer4.Stop();
    timer4.ResetCounter();
    // Включим все светодиоды
    leds.LedsOn();
}

// Функция для исполнения FooStage 
void FooStage_execute(){
    // Периодическое чтение данных для поддержания температуры кристалла датчиков
    // Возможно, это излишне
    sensor_L3GD20.ReadData();
    sensor_LSM303DLHC.ReadData();
}

// -------------------------------------------------------------------------------

// Функция для инициализации CalibrationStage
void CalibrationStage_init(){
    // Выключим все таймеры
    timer3.Stop();
    timer3.ResetCounter();
    timer4.Stop();
    timer4.ResetCounter();

    // Включим таймер для индикации работы и оба синих светодиода 
    leds.LedsOff();
    leds.LedOn(LED5);
    leds.LedOn(LED8);
    timer4.Start();

}

// Функция для исполнения CalibrationStage 
void CalibrationStage_execute(){

    // Задержка, чтобы отсечь колебания установки от нажатие кнопки оператором
    Delay(2000);

    // Запустим инициализацию масштабирующего коэффициента датчиков
    sensor_L3GD20.InitGyroScaller();
    sensor_LSM303DLHC.InitAccScaller();

    Delay(500);     // Сделаем небольшую паузу перед отправкой сообщения, чтобы ПК успел разобрать предыдущие посылки
    send_end_of_calibration_msg();
    program_stage_queue.put(&FooStage);
}

// -------------------------------------------------------------------------------

// Функция для инициализации StaticStage
void StaticStage_init(){
    tick_counter = 0;
    sensor_reading_counter = 0;
    leds.LedsOff();
    leds.LedOn(LED4);
    leds.LedOn(LED9);
    timer4.ResetCounter();
    timer4.Start();
}

// Функция для исполнения StaticStage
void StaticStage_execute(){

    // Задержка, чтобы отсечь колебания установки от нажатие кнопки оператором
    Delay(2000);

    // Сбросим фильтры перед сбором данных
    filter_acc.reset();
    filter_gyro.reset();
    filter_temp.reset();

    for(int i = 0; i < InitFrameNum; i++){

        /* ***************************************************************
        * Параметры фильтров подобраны так, что все фильтры готовятся за 
        * одинаковое число итераций, что критически важно для корректности 
        * отработки цикла!
        *************************************************************** */

        while(!filter_acc.is_data_filtered() || !filter_gyro.is_data_filtered() || !filter_temp.is_data_filtered()){
            // Считаем значения и добавим полученные значения в фильтры
            sensor_L3GD20.ReadGyro();
            filter_gyro.append_value(sensor_L3GD20.gyro_data);
            
            sensor_LSM303DLHC.ReadAcc();
            filter_acc.append_value(sensor_LSM303DLHC.acc_data);

            // Данные температуры будем считывать в 4 раза реже
            if (sensor_reading_counter++ % 4 == 0) {
                sensor_LSM303DLHC.ReadTemp();
                filter_temp.append_value(sensor_LSM303DLHC.temperature);
            }
        }

        // Обновим данные с датчиков
        acc_value = filter_acc.get_filtered_data();
        gyro_value = filter_gyro.get_filtered_data();
        temp_value = filter_temp.get_filtered_data();

        // Обновим данные в посылке и отправим её по com-порту
        telega_package.UpdateData();
        telega_package.UpdateControlSum();
        com_port.SendPackage(telega_package);

        // Сбросим фильтры
        filter_acc.reset();
        filter_gyro.reset();
        filter_temp.reset();
    }

    // В конце отправим сообщение об окончании выставки
    Delay(500);     // Сделаем небольшую паузу перед отправкой сообщения, чтобы ПК успел разобрать предыдущие посылки
    send_end_of_static_init_msg();
    program_stage_queue.put(&FooStage);
}

// -------------------------------------------------------------------------------

// Функция для инициализации MeasuringStage
void MeasuringStage_init(){
    tick_counter = 0;
    sensor_reading_counter = 0;
    leds.LedsOff();
    // Запустим таймер сбора данных с частотой 4 Гц
    timer3.ResetCounter();
    timer3.Start();
    // Запустим таймер индикации работы
    timer4.ResetCounter();
    timer4.Start();
}

// Функция для исполнения MeasuringStage 
void MeasuringStage_execute(){
    leds.ChangeLedStatus(LED8);

    if (timer_tick_flag){

        /* ***********************************************************************
        * ВАЖНО! Длительность выполнения этой стадии не должна превышать 200мс
        * для обеспечения выдачи данных с частотой 4 Гц. Длительность выполнения
        * можно менять с помощью шаблонных параметров NSigmaFilter.
        *********************************************************************** */

        leds.LedOn(LED5);

        while(!filter_acc.is_data_filtered() || !filter_gyro.is_data_filtered() || !filter_temp.is_data_filtered()){
            // Считаем значения и добавим полученные значения в фильтры
            sensor_L3GD20.ReadGyro();
            filter_gyro.append_value(sensor_L3GD20.gyro_data);

            sensor_LSM303DLHC.ReadAcc();
            filter_acc.append_value(sensor_LSM303DLHC.acc_data);

            // Данные температуры будем считывать в 4 раза реже
            if (sensor_reading_counter++ % 4 == 0) {
                sensor_LSM303DLHC.ReadTemp();
                filter_temp.append_value(sensor_LSM303DLHC.temperature);
            }
        }

        // Обновим данные с датчиков
        acc_value = filter_acc.get_filtered_data();
        gyro_value = filter_gyro.get_filtered_data();
        temp_value = filter_temp.get_filtered_data();

        // Обновим данные в посылке и отправим её по com-порту
        telega_package.UpdateData();
        telega_package.UpdateControlSum();
        com_port.SendPackage(telega_package);

        // Сбросим фильтры
        filter_acc.reset();
        filter_gyro.reset();
        filter_temp.reset();

        leds.LedOff(LED5);
        timer_tick_flag = false;
    }
}

// -------------------------------------------------------------------------------
// Функции для отработки поступивших команд
// -------------------------------------------------------------------------------

void UserEP3_OUT_Callback(uint8_t *buffer){
    Messages::SizedMessage<VCP_BUFFER_SIZE> message(buffer, VCP_BUFFER_SIZE);
    com_port.EP3_OUT_Callback(message);
}

// Функции для обработки поступивших команд
void restart(){
    NVIC_SystemReset();
}

void set_FooStage(){
    program_stage_queue.put(&FooStage);
}

void set_CalibrationStage(){
    program_stage_queue.put(&CalibrationStage);
}

void set_StaticStage(){
    program_stage_queue.put(&StaticStage);;
}

void set_MeasureStage(){
    program_stage_queue.put(&MeasuringStage);
}

// -------------------------------------------------------------------------------
// Отправка предопределённых сообщений
// -------------------------------------------------------------------------------


void send_confirm_msg(){
    const char* text = "CONFIRM_RECEIVED_COMMAND";
    Packages::MessagePackage msg_package(text, strlen(text));
    com_port.SendPackage(msg_package);
}

void send_handshake_ack(){
    const char* text = "TELEGA_STM32_ACK";
    Packages::MessagePackage msg_package(text, strlen(text));
    com_port.SendPackage(msg_package);
}

void send_heartbeat_ack(){
    const char* text = "TELEGA_STM32_ALIVE";
    Packages::MessagePackage msg_package(text, strlen(text));
    com_port.SendPackage(msg_package);
}

void send_error_msg(){
    const char* text = "UNKNOWN_COMMAND";
    Packages::MessagePackage msg_package(text, strlen(text));
    com_port.SendPackage(msg_package);
}

void send_end_of_calibration_msg(){
    const char* text = "END_OF_CALIBRATION";
    Packages::MessagePackage msg_package(text, strlen(text));
    com_port.SendPackage(msg_package);
}

void send_end_of_static_init_msg(){
    const char* text = "END_OF_STATIC_INIT";
    Packages::MessagePackage msg_package(text, strlen(text));
    com_port.SendPackage(msg_package);
}

// -------------------------------------------------------------------------------
// Системные функции
// -------------------------------------------------------------------------------

void Error_Handler(void)
{
    /* Turn LED10/3 (RED) on */
    STM_EVAL_LEDOn(LED10);
    STM_EVAL_LEDOn(LED3);
    while (1)
    {
    }
}

// Function to insert a timing delay of nTime
// ###### DO NOT CHANGE ######
void Delay(__IO uint32_t nTime)
{
    TimingDelay = nTime;

    while (TimingDelay != 0){}
    // for (int i = 0; i < 1000000; i++){}
}

// Function to Decrement the TimingDelay variable.
// ###### DO NOT CHANGE ######
void TimingDelay_Decrement(void)
{
    if (TimingDelay != 0x00)
    {
        TimingDelay--;
    }
}

// Unused functions that have to be included to ensure correct compiling
// ###### DO NOT CHANGE ######
// =======================================================================
uint32_t L3GD20_TIMEOUT_UserCallback(void)
{
    return 0;
}

uint32_t LSM303DLHC_TIMEOUT_UserCallback(void)
{
    return 0;
}
// =======================================================================

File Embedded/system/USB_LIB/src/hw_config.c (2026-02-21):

/**
 ******************************************************************************
 * @file    hw_config.c
 * @author  MCD Application Team
 * @version V1.1.0
 * @date    20-September-2012
 * @brief   Hardware Configuration & Setup.
 ******************************************************************************
 * @attention
 *
 * <h2><center>&copy; COPYRIGHT 2012 STMicroelectronics</center></h2>
 *
 * Licensed under MCD-ST Liberty SW License Agreement V2, (the "License");
 * You may not use this file except in compliance with the License.
 * You may obtain a copy of the License at:
 *
 *        http://www.st.com/software_license_agreement_liberty_v2
 *
 * Unless required by applicable law or agreed to in writing, software
 * distributed under the License is distributed on an "AS IS" BASIS,
 * WITHOUT WARRANTIES OR CONDITIONS OF ANY KIND, either express or implied.
 * See the License for the specific language governing permissions and
 * limitations under the License.
 *
 ******************************************************************************
 */

/* Includes ------------------------------------------------------------------*/
#include "stm32f30x.h"
#include "hw_config.h"
#include "usb_lib.h"
#include "usb_desc.h"
#include "usb_pwr.h"
#include "usb_lib.h"
#include "platform_config.h"
#include "stm32f3_discovery.h"
#include "usb_prop.h"

#include "stm32f30x_it.h"
#include "stm32f30x_gpio.h"
#include "stm32f30x_exti.h"
#include "stm32f30x_rcc.h"
#include "stm32f30x_misc.h"
#include "usb_lib.h"
#include "usb_prop.h"
#include "usb_desc.h"
#include "hw_config.h"
#include "usb_pwr.h"

/** @addtogroup STM32F3-Discovery_Demo
 * @{
 */

/* Private typedef -----------------------------------------------------------*/
/* Private define ------------------------------------------------------------*/
/* Private macro -------------------------------------------------------------*/
/* Private variables ---------------------------------------------------------*/
ErrorStatus HSEStartUpStatus;
EXTI_InitTypeDef EXTI_InitStructure;

extern __IO uint32_t packet_sent;
extern __IO uint8_t Send_Buffer[VIRTUAL_COM_PORT_DATA_SIZE];
extern __IO uint32_t packet_receive;
extern __IO uint8_t Receive_length;

__IO uint8_t Receive_Buffer[64] = {0};
uint32_t Send_length;

__IO uint32_t packet_sent;
__IO uint32_t packet_receive;

/* Extern variables ----------------------------------------------------------*/
extern __IO uint8_t PrevXferComplete;

extern LINE_CODING linecoding;

/* Private function prototypes -----------------------------------------------*/
static void IntToUnicode(uint32_t value, uint8_t *pbuf, uint8_t len);
/* Private functions ---------------------------------------------------------*/

/**
 * @brief  Configures Main system clocks & power.
 * @param  None
 * @retval None
 */
void Set_System(void)
{
    GPIO_InitTypeDef GPIO_InitStructure;

    /*!< At this stage the microcontroller clock setting is already configured,
         this is done through SystemInit() function which is called from startup
         file (startup_stm32f30x.s) before to branch to application main.
         To reconfigure the default setting of SystemInit() function, refer to
         system_stm32f30x.c file
       */

    /* Enable the PWR clock */
    RCC_APB1PeriphClockCmd(RCC_APB1Periph_PWR, ENABLE);

    /* Enable the SYSCFG module clock (used for the USB disconnect feature) */

    RCC_APB2PeriphClockCmd(RCC_APB2Periph_SYSCFG, ENABLE);

    /* Enable the USB disconnect GPIO clock */
    RCC_AHBPeriphClockCmd(RCC_AHBPeriph_GPIO_DISCONNECT, ENABLE);

    /*Set PA11,12 as IN - USB_DM,DP*/

    RCC_AHBPeriphClockCmd(RCC_AHBPeriph_GPIOA, ENABLE);
    GPIO_InitStructure.GPIO_Pin = GPIO_Pin_11;
    GPIO_InitStructure.GPIO_Speed = GPIO_Speed_50MHz;
    GPIO_InitStructure.GPIO_Mode = GPIO_Mode_AF;
    GPIO_InitStructure.GPIO_OType = GPIO_OType_PP;
    GPIO_InitStructure.GPIO_PuPd = GPIO_PuPd_DOWN;
    GPIO_Init(GPIOA, &GPIO_InitStructure);

    RCC_AHBPeriphClockCmd(RCC_AHBPeriph_GPIOA, ENABLE);
    GPIO_InitStructure.GPIO_Pin = GPIO_Pin_12;
    GPIO_InitStructure.GPIO_PuPd = GPIO_PuPd_UP;
    GPIO_Init(GPIOA, &GPIO_InitStructure);

    /*SET PA11,12 for USB: USB_DM,DP*/
    GPIO_PinAFConfig(GPIOA, GPIO_PinSource11, GPIO_AF_14);
    GPIO_PinAFConfig(GPIOA, GPIO_PinSource12, GPIO_AF_14);
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

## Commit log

2025-10-16 Собрал все файлы из разных директорий в одно место
    [Connectors.kicad_sch, MAX3232.kicad_sch, PowerLedSheme.kicad_sch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]
2025-10-16 Выровнял посадочные места на плате
    [Telega_KiCad.kicad_pcb]
2025-10-16 Сохранение файлов программы
2025-10-16 Создал первую эскизную сборку
2025-10-16 Обновил gitignore
2025-10-21 Начал проектировать второй вариант корпуса
2025-10-30 Обрезал основание платы под крепление в коробке
2026-01-27 Редактирование платы
    Я не помню, что тут изменил...
    [Список комплектующих.csv]
2026-01-27 Спроектировал переднюю панель
2026-01-27 Изменил gitignore
2026-01-29 Реализовал статическую очередь
2026-02-10 Перенёс все файлы из другого проекта
2026-02-12 Реализовать NSigmaFilter
2026-02-12 Рефакторинг файлов для работы с таймерами
2026-02-13 Переделал выполнение switch (stage)
2026-02-13 Небольшой рефакторинг main.cpp
2026-02-16 Добавил декодер получаемых сообщений
2026-02-17 Реализовал поддержку float в классе NSigmaFilter для фильтрации температуры из main
2026-02-17 Изменил название директории
    [stm32f3discovery.cfg]
2026-02-17 Получилось собрать проект
2026-02-18 Модифицировал классы Message и TriaxialData
2026-02-19 Убрал лишние файлы
2026-02-19 Рефакторинг
2026-02-24 Обновил TriaxialData
2026-02-27 Добавил пакет decoding для более удобного декодирования входного потока данных
2026-02-27 Проверил работоспособность с дополнительным декодером
2026-02-27 Изменил вычисление длины полезных данных в пакете данных
2026-03-16 Начал создание алгоритма расчёта траектории движения
2026-03-16 Доработал модель передней панели
2026-03-16 Создал модели крепления АКБ и корпуса к телеге
2026-03-31 Реализовал описанный в дипломе алгоритм построения траектории движения
2026-04-03 Перенёс дополнительные файлы
2026-05-06 Перенёс файлы из AsyncMCController/Embedded
2026-05-06 Исправил инициализацию VCP
2026-05-06 Исправил ACK сообщения
2026-05-06 Уменьшил габариты панели и добавил фаски
2026-05-06 Добавил CalibrationStage для установления масштабирующего коэффициента датчиков
    Вызывается по бинарной команде 0xaa, 0x01
2026-05-06 Исправил ошибки для корректной сборки
2026-05-11 Добавил send_end_of_calibration_msg и изменил список срочных команд
2026-05-12 Обновил крепления к тележке
2026-05-13 Исправил получаемые команды
2026-05-14 Доработана логика выполнения стадий программ
2026-05-14 Обновил размеры на лицевой панели
2026-05-19 Добавил использование датчика ДПП
2026-05-19 Сгенерировал readme с описанием архитектуры прошивки
2026-05-19 Перенёс файлы из Telega_GUI_v2
2026-05-19 Обновлён README.md с описанием структуры GUI и обновлён .gitignore
    Перед началом работы в других ветках необходимо выполнить merge master
2026-05-20 Сгенерировал код для реализации навигационного алгоритма
2026-05-21 Вынес опрос ДПП через таймер
2026-05-21 Изменил параметры гироскопа
2026-05-22 Добавил сохранение температуры в csv файл и убрал вывод логгера в консоль
2026-05-23 Сгенерировал файл для запуска пайплайна
2026-05-28 Добавлены файлы для обработки файлов
2026-05-28 Исправил выравнивание таблицы векторов прерывания и инициализацию EXTI
    [main.cpp]
2026-07-28 Изменения в прошивке для отправки сырых данных
2026-07-28 Добавил индикацию чтения датчиков и убрал стадию калибровки
2026-07-29 Настроил сборку проекта и его загрузку через скрипты
    Пользовательский settings.json задаёт параметры инструментов сборки и отладки
2026-07-30 Добавлена информация по сборке прошивки
2026-07-30 Переработал механизм отправки команд между процессами
2026-07-30 Реализована отправка в responce_queue объектов SessionEvent, а не сырых строк
2026-07-30 Убрана стадия калибровки из Python части проекта
2026-07-30 Переработан com_port_reader.py
2026-08-03 Перенёс хранилище в async_mc_controller процесс и переработал com_port_reading.py
2026-08-03 Переработан MainWindow и вынесена часть логики в program_stages
2026-08-03 Изменена семантика REQ-запросов
2026-08-04 Убраны Qt механизмы в отдельных файлах
2026-08-05 Реализованы единые *_RESULT и более аккуратная отправка информации
2026-08-05 Добавлены сигналы DRAIN_PACKAGES и ENABLE_PACKAGE_PUBLISHING
    Они используются для управления публикации полученных пакетов данных
2026-08-06 Codex что-то начал переделывать в com_port_reader.py
2026-08-06 Переписал _SessionProcessTransport.shutdown
2026-08-06 Переделал взаимодействие между MainWindow и ComPortReader
2026-08-06 Проверил сгенеренный код
    Вроде норм, но надо до конца убедиться
2026-08-07 Добавлен файл с описанием архитектуры проекта
2026-08-07 Исправлены ошибки при запуске программы
2026-08-07 Небольшой рефакторинг
2026-08-07 Добавил сброс буфера COM порта при STOP_MEASURING
2026-08-10 Немного изменил сборку
2026-08-10 Изменил в tasks.json вызов скриптов по относительному пути
2026-08-19 Исправлен flash.sh
2026-10-21 Исправил инициализацию акселерометра
2026-10-21 Теперь значения акселерометра выдаются в mg
    Так что теперь необходимо проводить перевод на компе
2026-10-21 Сделал частоту работу в MeasuringStage 200 Гц

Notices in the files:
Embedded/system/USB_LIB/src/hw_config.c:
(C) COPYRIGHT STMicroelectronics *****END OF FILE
